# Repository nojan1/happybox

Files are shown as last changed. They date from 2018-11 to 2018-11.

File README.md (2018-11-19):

Happybox
=========

# 1. Getting up and running

To start using the happybox you need to connect it to a network (1.1) (internet access may or may not be requried). You may then need to write an implementation that takes the data from the buttons and forwards it to an external service (1.2).

## 1.1 Wifi
To configure the wifi create a file called `wpa_supplicant.conf` on the SD-Card boot partition (FAT32). 

Enter the following:
```
update_config=1
ctrl_interface=/var/run/wpa_supplicant

network={
 scan_ssid=1
 ssid="RouterName"
 psk="Security"
}
```

The example is for a standard WPA2-PSK network. For more exotic networks, refer to the wpa_supplicant man page.

## 1.2 Actual implementation

By default the happybox software is set up to write happiness data to a file. This is not particulary usefull and you will most likely need to implement a better solution. 

This is done by coping the file "implementation_skeleton.py" to a new implementation file, for example "implementation_rest.py". You will then need to open the file "main.py" and change the top import statement so that it refers to the new file.

Your implementation will derive from *ImplementationBase* and must override the following methods.

| Method | Returns | Arguments | Description |
|-----|-----|-----|---|
| AllGood | bool | N/A | Return true if all is good and results can be forwarded |
| HandleValue | nothing | buttonNumber:int, errorDetected:callback | Handle a value generated by a keypress on the happiness buttons  |

# 2 Hardware

The hardware inside the happybox is consists of a Raspberry Pi Zero W which acts as the brain.

To this the following things are connected:
 * Four buttons
 * Four 16 pixel Neopixel rings

# 3 Software

The base software is written in python using the Adafruit CircuitPython libraries to interface with the Pi hardware pins. 

To control the Neopixel rings it utilises the rpi_ws281x library by jgarff. This library makes use of the Pi's PWM and DMA functionality to handle the complex timing required.

The software is programmed to react to button presses from the four "happiness" buttons and to the forward this to an external service. See section 1.2 for more information about where the data ends up.

# 4 Setting up from scratch

These instructions are usefull if you have an blank SD-Card and wish to get Happybox up and running.

## 4.1 Install Rasbian

Install Rasbian according to instructions on the [official page](https://www.raspberrypi.org/documentation/installation/installing-images/README.md).

After install setup Wifi (section 1.1), SSH and/or Serial access.

### 4.1.1 Enabling SSH

Create a file called `ssh` on the "/boot" partition. This will automatically enable the SSH server on first startup.

You can now use a SSH-client like Putty to connect.

### 4.2.1 Enable serial terminal

Access to the pi can be made without networking by instead using an old school serial terminal. Please note that this requires use of a **3,3v** UART adapter.

Enable the serial console functionality by adding the following line to the file `/boot/config.txt`.

```
enable_uart=1
```

After this make sure that the line `serial0,11520` appears in the file `/boot/cmdline.txt`

You can now connect the UART adapter by attaching the pins according to the table below:

| UART Pin | Pi pin number |
|---|---|
| GND  | 6  |
| RX  | 8 |
| TX  | 10  |

Connect USB-power to the PI and connect using a serial terminal on the correct port with a baudrate of 11520.

## 4.2 Installing Dependencies

Run the commands below to install python and all reguired dependencies.

```
sudo apt-get install python3 python3-pip git scons python3-dev swig
sudo pip3 install RPI.GPIO
sudo pip3 install adafruit-circuitpython-neopixel 
```

The following commands installs the library required for Neopixels to work.

```
git clone https://github.com/jgarff/rpi_ws281x.git
cd rpi_ws281x
scons
cd python
python3 ./setup.py build
sudo python3 ./setup.py install
```
## 4.3 Setting up the happybox software

```
git clone https://github.com/nojan1/happybox.git
cd happybox/root
sudo cp -R * /
sudo systemctl enable happybox
sudo systemctl start happybox
```

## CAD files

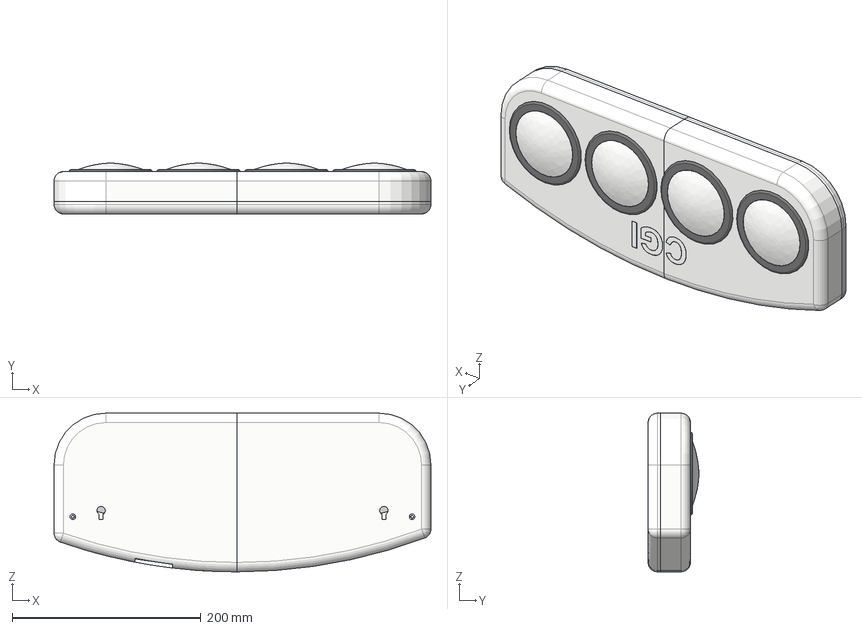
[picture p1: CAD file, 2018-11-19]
resources/cad/step/assembly.stp
400.0 x 54.0 x 168.4 mm
LED Ring v3 x 4
Dome x 4
Button for alt 3 x 4
RaspberryPiZeroW
Parts - PCB
Parts - micro_B

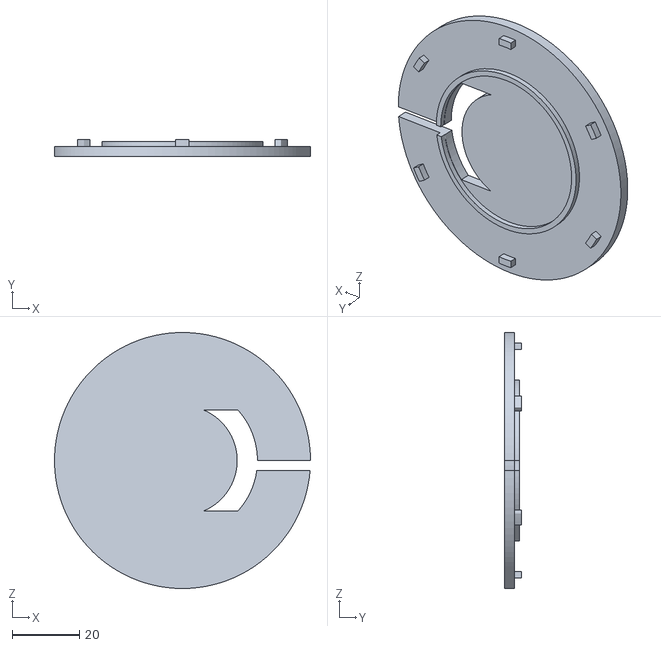
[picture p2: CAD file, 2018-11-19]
resources/cad/stl/Button/sliding-plate.stl
76.0 x 5.00 x 76.0

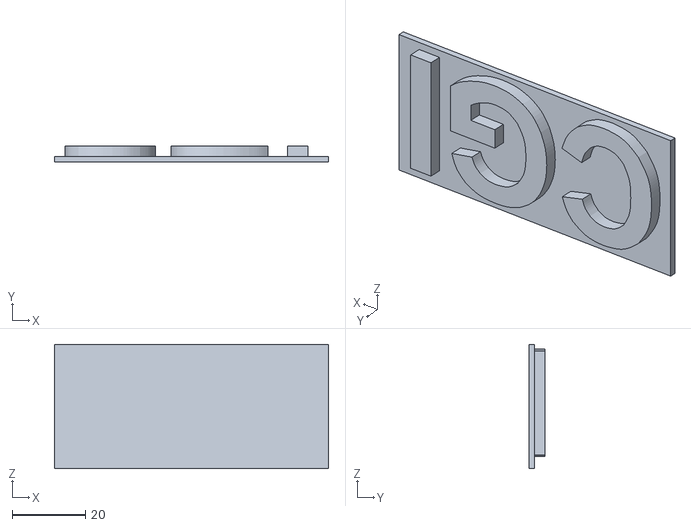
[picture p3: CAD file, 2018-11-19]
resources/cad/stl/Letter diffuse inlay.stl
74.9 x 4.50 x 34.0

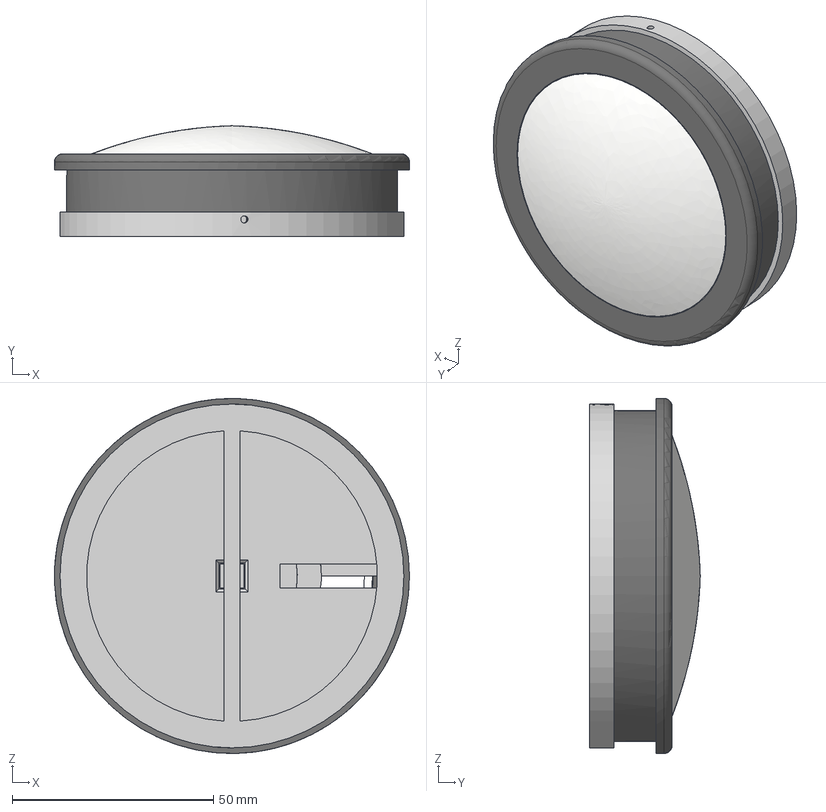
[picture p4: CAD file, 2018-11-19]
resources/cad/step/button.stp
88.3 x 27.5 x 88.3 mm
LED Ring v3
Dome
Button for alt 3

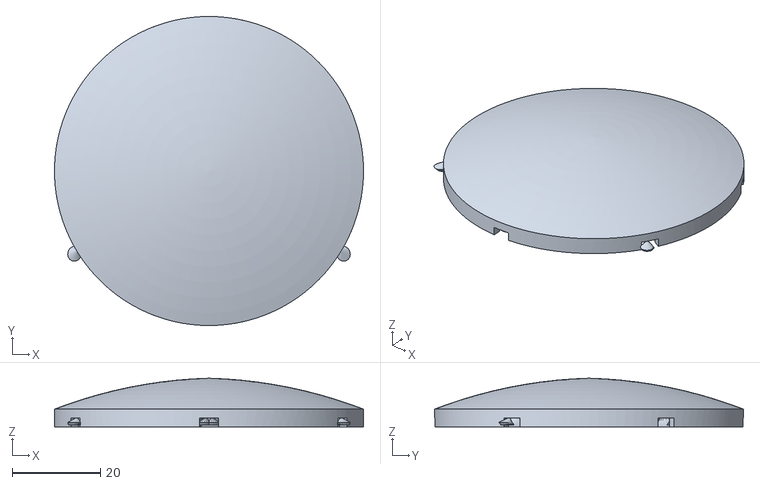
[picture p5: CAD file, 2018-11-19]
resources/cad/stl/Button/Dome.supports.stl
69.9 x 69.9 x 11.0

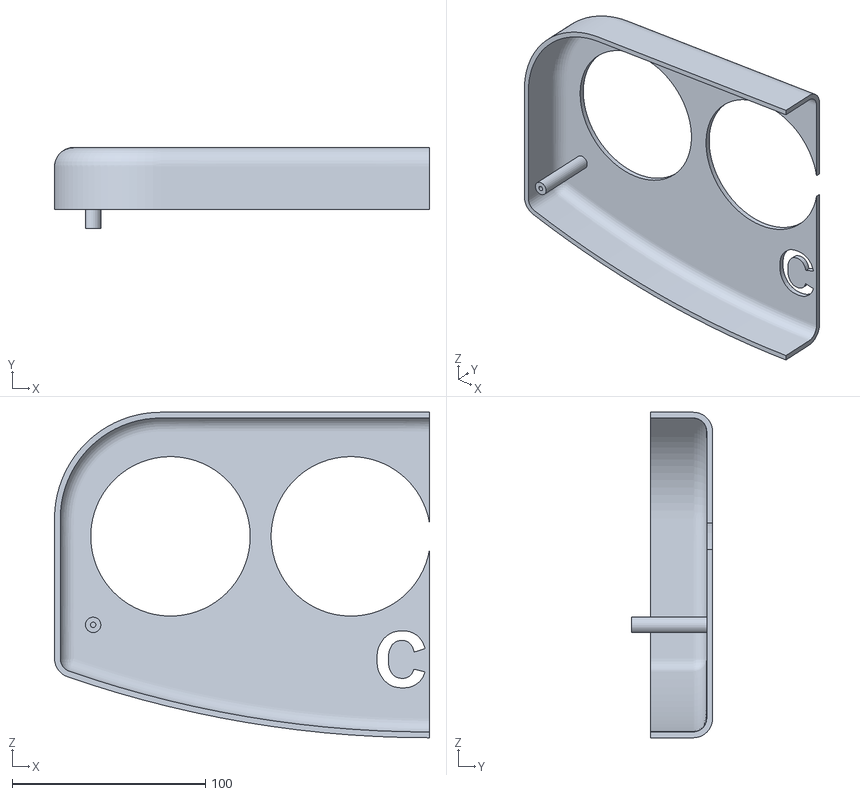
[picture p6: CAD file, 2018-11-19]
resources/cad/stl/Top left.stl
194.0 x 42.0 x 168.4

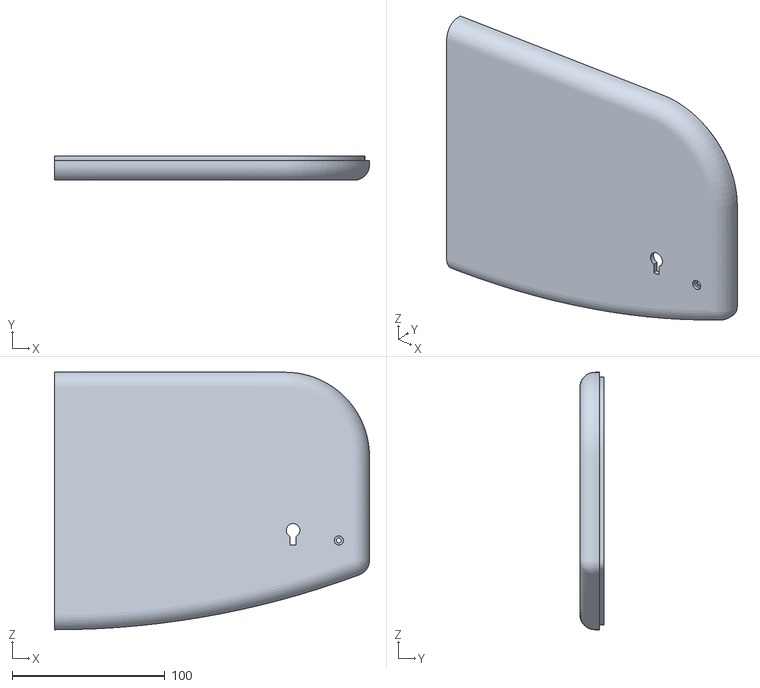
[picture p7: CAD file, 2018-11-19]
resources/cad/stl/Bottom_right.stl
206.0 x 16.0 x 168.4

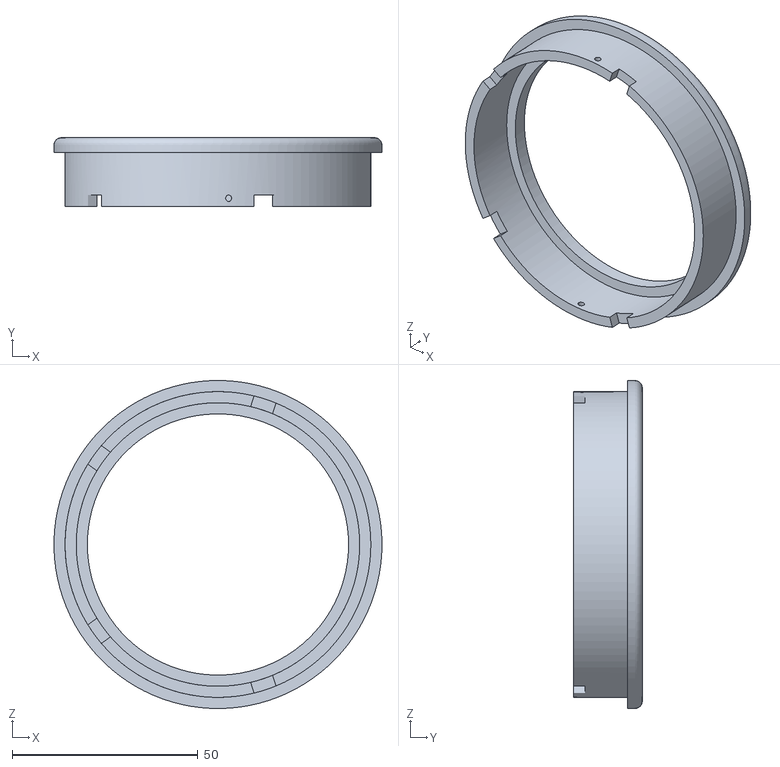
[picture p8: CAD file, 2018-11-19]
resources/cad/stl/Button/body.stl
88.3 x 18.5 x 88.3

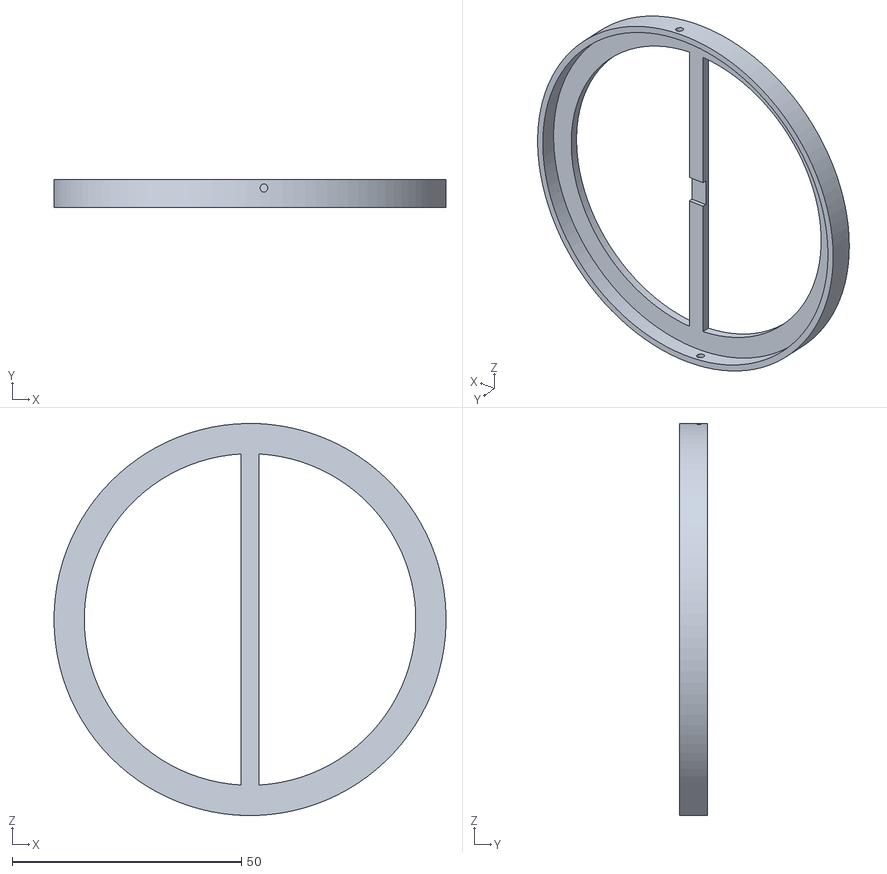
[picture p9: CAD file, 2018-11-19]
resources/cad/stl/Button/locking-ring.stl
85.5 x 6.00 x 85.5

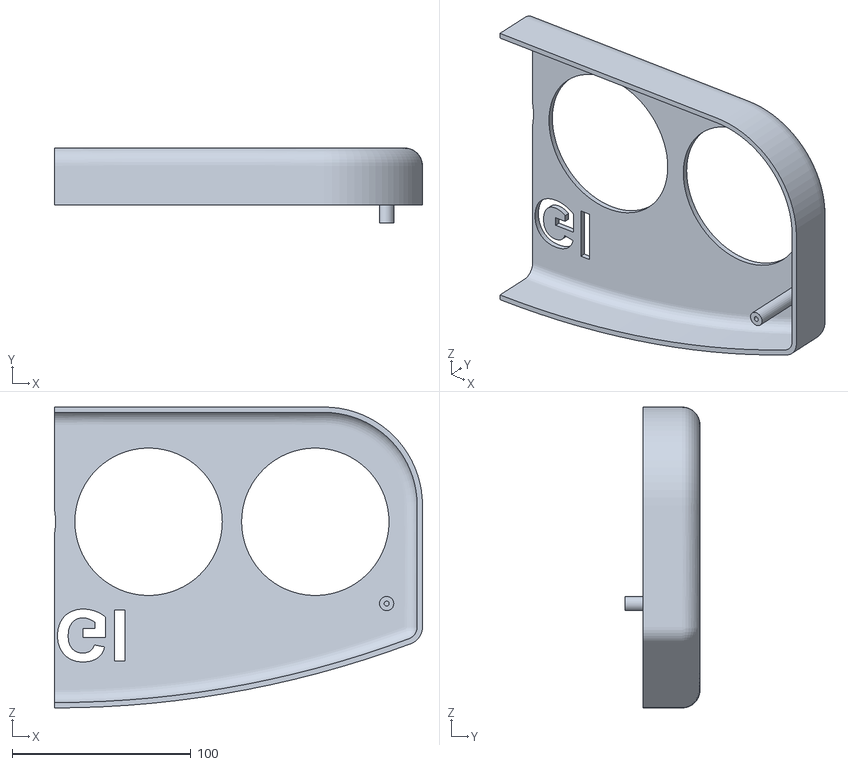
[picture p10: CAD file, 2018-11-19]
resources/cad/stl/Top right.stl
206.0 x 42.0 x 168.4

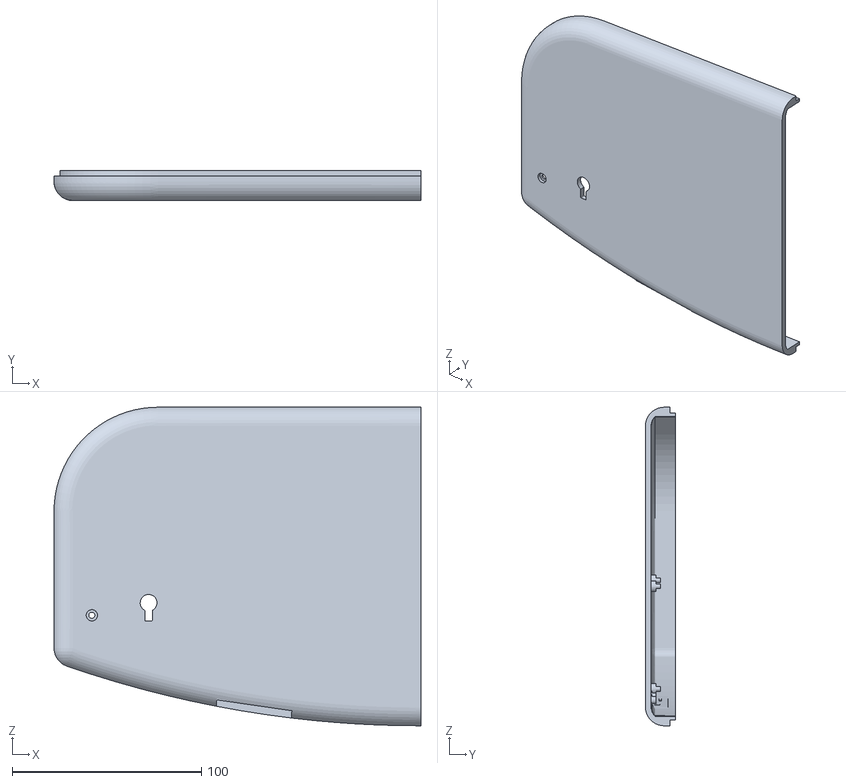
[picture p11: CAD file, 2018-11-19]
resources/cad/stl/Bottom_left.stl
194.0 x 16.0 x 168.4

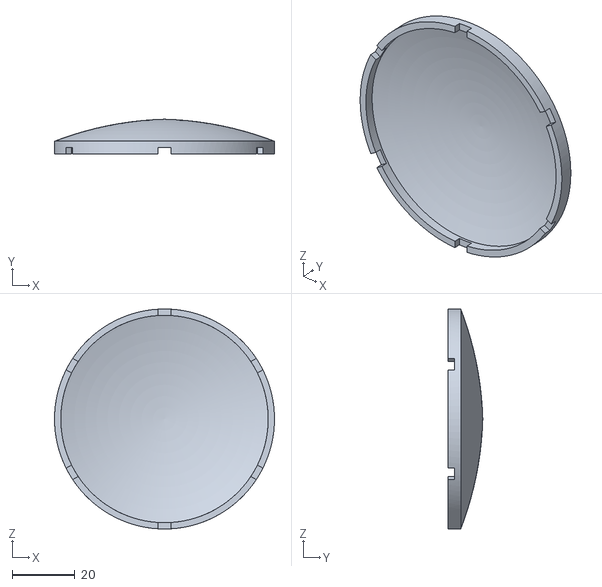
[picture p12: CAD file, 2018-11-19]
resources/cad/stl/Button/Dome.stl
69.9 x 11.0 x 69.9

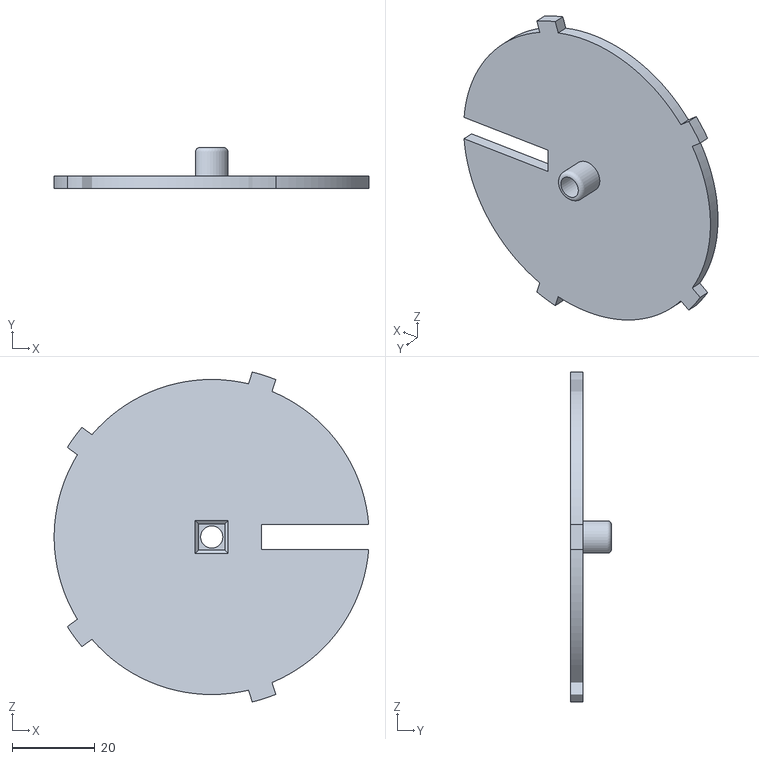
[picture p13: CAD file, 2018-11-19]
resources/cad/stl/Button/bottom-plate.stl
76.2 x 9.90 x 79.9

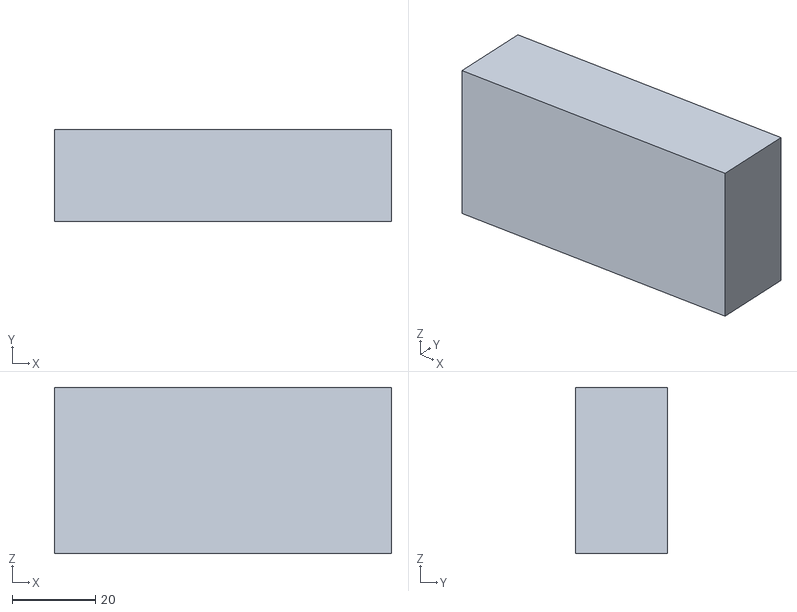
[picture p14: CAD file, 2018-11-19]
resources/cad/stl/Led box.stl
80.9 x 22.0 x 40.0

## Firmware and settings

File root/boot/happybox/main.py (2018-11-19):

# Change this line to import the correct implementation
from implementation_file import Implementation

##### No need to change anything below ######
from button import Button

import time
import board
import neopixel
import digitalio

NUM_PIXELS = 64
STEP_DELAY = 0.1
ALL_GOOD_CHECK_DELAY = 60

buttons = [Button(x) for x in [board.D17, board.D22, board.D27, board.D24]]

logo = digitalio.DigitalInOut(board.D23)
logo.direction = digitalio.Direction.OUTPUT
logo.value = True

implentation = Implementation()

pixels = neopixel.NeoPixel(
    board.D18, NUM_PIXELS, brightness=0.2, auto_write=False, pixel_order=neopixel.GRB)

factors = [1, 0.95, 0.90, 0.85, 0.80, 0.75, 0.70, 0.65, 0.60, 0.55, 0.50, 0.45]
baseColors = [(0, 255, 0), (255, 200, 0), (255, 50, 0), (255, 0, 0)]
lastStep = 0
offset = 0
offsetDirection = 1

lastAllGoodCheck = 0
allGood = False

def onImplementationError():
    global allGood
    allGood = False


def ledAnimationCycle():
    global pixels, baseColors, factors, STEP_DELAY, NUM_PIXELS, offset, offsetDirection, lastStep

    if time.time() - lastStep > STEP_DELAY:
        for i in range(NUM_PIXELS):
            red = baseColors[i // 16][0] * factors[offset]
            green = baseColors[i // 16][1] * factors[offset]
            blue = baseColors[i // 16][2] * factors[offset]

            pixels[i] = (int(red), int(green), int(blue))

        pixels.show()
        lastStep = time.time()

        offset += offsetDirection

        if offset == len(factors) - 1:
            offsetDirection = -1
        elif offset == 0:
            offsetDirection = +1


def buttonPressAnimation(buttonNumber):
    global pixels, baseColors
    pixels.fill((0, 0, 0))

    for i in range(2):
        for i in range(8):
            pixels[i + (buttonNumber * 16)] = baseColors[buttonNumber]
            pixels[i + 8 + (buttonNumber * 16)] = baseColors[buttonNumber]
            pixels.show()

            time.sleep(0.015)

        for i in range(8):
            pixels[i + (buttonNumber * 16)] = (0, 0, 0)
            pixels[i + 8 + (buttonNumber * 16)] = (0, 0, 0)
            pixels.show()

            time.sleep(0.015)


def checkButtons():
    global buttons, implentation
    for i, button in enumerate(buttons):
        if button.IsPressed():
            print("Button " + str(i) + " is pressed")
            implentation.HandleValue(i, onImplementationError)
            buttonPressAnimation(i)


def checkAllGood():
    global lastAllGoodCheck, implentation, allGood 
    if time.time() - lastAllGoodCheck > ALL_GOOD_CHECK_DELAY:
        allGood = implentation.AllGood()
        lastAllGoodCheck = time.time()


def main():
    global pixels, logo

    pixels.fill((0, 0, 0))
    pixels.show()

    while True:
        checkAllGood()

        if allGood:
            logo.value = True

            ledAnimationCycle()
            checkButtons()
            time.sleep(0.002)
        else:
            logo.value = not logo.value
            time.sleep(0.1)


if __name__ == "__main__":
    main()

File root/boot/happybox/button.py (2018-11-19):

import digitalio
import time

DEBOUNCE_TIME = 0.05

class Button(object):
    def __init__(self, pin):
        self.button = digitalio.DigitalInOut(pin)
        self.button.direction = digitalio.Direction.INPUT
        self.button.pull = digitalio.Pull.UP

        self.timeDown = None
        self.inhibit = False

    def IsPressed(self):
        if not self.button.value:
            if self.timeDown == None:
                self.timeDown = time.time()
            elif time.time() - self.timeDown >= DEBOUNCE_TIME and not self.inhibit:
                self.inhibit = True
                return True
        else:
            self.inhibit = False
            self.timeDown = None

        return False

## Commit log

2018-11-19 Ported Arduino code for color animation logic
2018-11-19 Added schematic
    [connections.sch]
2018-11-19 Added step files
    [assembly.stp, button.stp]
2018-11-19 Added STL's
    [Bottom_left.stl, Bottom_right.stl, Dome.stl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]
